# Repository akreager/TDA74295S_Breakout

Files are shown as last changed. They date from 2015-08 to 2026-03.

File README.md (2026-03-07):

# TDA7429 Breakout Board & Arduino Library

Breakout board and Arduino library for the ST TDA7429 digitally controlled audio processor with surround sound matrix.

## What is the TDA7429?

The TDA7429 is an I²C-controlled audio DSP designed for TV and Hi-Fi systems. It handles input selection, volume/tone control, surround sound processing, and speaker balance — all through a two-wire serial bus with no external microcontroller overhead beyond simple register writes.

**Key specs:**
- 3 stereo inputs with 0–31.5 dB attenuation (0.5 dB steps)
- Bass, middle, and treble control (±14 dB, 2 dB steps)
- 4 independent speaker attenuators (0–79 dB, 1 dB steps + mute)
- 3 surround modes: music, movie, simulated (256 selectable responses)
- 4 programmable phase shifters
- Monitor and auxiliary outputs
- 106 dB signal-to-noise ratio
- 7–10.2 V supply

## Repository Structure

```
├── pcb/
│   ├── TDA7429_BREAKOUT.kicad_pro      # KiCad project
│   ├── TDA7429_BREAKOUT.kicad_sch      # Schematic
│   ├── TDA7429_BREAKOUT.kicad_pcb      # PCB layout
│   ├── fp-lib-table                    # Footprint library table
│   ├── sym-lib-table                   # Symbol library table
│   ├── eagle2kicad_pcb.py              # Board conversion script
│   ├── eagle2kicad_sch.py              # Schematic conversion script
│   ├── TDA7429_KiCad_Lib/             # Custom KiCad library
│   │   ├── TDA7429.kicad_sym
│   │   └── TDA7429.pretty/
│   │       └── SDIP-42_W15.24mm_P1.778mm.kicad_mod
│   └── Archive Eagle Design/           # Original Eagle 6.5 files
│       ├── TDA7429_BREAKOUT.sch
│       ├── TDA7429_BREAKOUT.brd
│       └── TDA7429_BREAKOUT.pdf
├── TDA7429S TDA7429T.pdf               # Datasheet
├── .gitattributes
├── .gitignore
└── README.md
```

## Hardware

### Breakout Board

~50 × 50 mm board carrying the TDA7429S (SDIP-42) with all external filter components from the datasheet reference circuit. Pin headers break out:

| Header | Pins |
|---|---|
| AUDIO_IN | 3 stereo input pairs (L/R × IN1–IN3) |
| AUDIO_OUT  | L_OUT, R_OUT, AUXOUT_L, AUXOUT_R |
| MONITOR | MONITOR_L, MONITOR_R |
| DATA | SDA, SCL |
| POWER | +9V, GND |

### Connecting to Arduino

| Breakout | Arduino Uno/Nano | Arduino Mega |
|---|---|---|
| SDA | A4 | 20 |
| SCL | A5 | 21 |
| GND | GND | GND |

The TDA7429 runs at 7–10.2 V — do **not** power it from the Arduino 5V pin. Use a separate 9V supply for the breakout board. The I²C bus needs pull-up resistors to the Arduino's 3.3V or 5V (4.7kΩ typical). The chip's I²C thresholds (V_IL max 1V, V_IH min 3V) are compatible with both 3.3V and 5V logic.

## Arduino Library

### Installation

Copy the `firmware/TDA7429/` folder into your Arduino libraries directory, or use the Arduino IDE Library Manager if published.

### Quick Start

```cpp
#include <Wire.h>
#include <TDA7429.h>

TDA7429 audio;

void setup() {
  Wire.begin();
  audio.begin();

  audio.selectInput(1);          // Input 1
  audio.setInputAttenuation(0);  // 0 dB (no attenuation)
  audio.setBass(0);              // Flat
  audio.setMiddle(0);            // Flat
  audio.setTreble(0);            // Flat
  audio.setSpeakerAttenuation(TDA7429_LEFT, -20);   // -20 dB
  audio.setSpeakerAttenuation(TDA7429_RIGHT, -20);  // -20 dB
  audio.setSurroundMode(TDA7429_SURROUND_OFF);
}

void loop() {
  // Adjust volume, tone, etc. from serial commands, buttons, encoder...
}
```

### API Reference

| Method | Description |
|---|---|
| `begin()` | Initialize with default (muted) state |
| `selectInput(1–4)` | Choose stereo input pair |
| `setInputAttenuation(dB)` | 0 to -31.5 dB in 0.5 dB steps |
| `setBass(dB)` | -14 to +14 dB in 2 dB steps |
| `setMiddle(dB)` | -14 to +14 dB in 2 dB steps |
| `setTreble(dB)` | -14 to +14 dB in 2 dB steps |
| `setSpeakerAttenuation(ch, dB)` | 0 to -79 dB per channel, 1 dB steps |
| `setAuxAttenuation(ch, dB)` | 0 to -79 dB per channel, 1 dB steps |
| `setSurroundMode(mode)` | OFF, MUSIC, MOVIE, SIMULATED |
| `setEffectControl(dB)` | -6 to -21 dB surround effect level |
| `setPhaseShifters(...)` | Configure 4 phase shift resistors |
| `mute()` / `unmute()` | Mute/unmute all speaker outputs |

## Known Issues / TODO

- [ ] DIG_GND (pin 28) needs to be connected to ground in the schematic
- [ ] Audio connector ground pins (L-, R-) need explicit connection to AGND
- [ ] Consider adding bottom ground pour for improved noise performance
- [ ] Add ferrite bead between DIG_GND and AGND for digital/analog isolation

## License

Hardware design files are released under [CERN-OHL-P v2](https://ohwr.org/cern_ohl_p_v2.txt). Arduino library is released under the MIT License. See individual directories for details.

## Credits

Board design by Allen Kreager. Originally designed in Eagle 6.5, converted to KiCad 7.

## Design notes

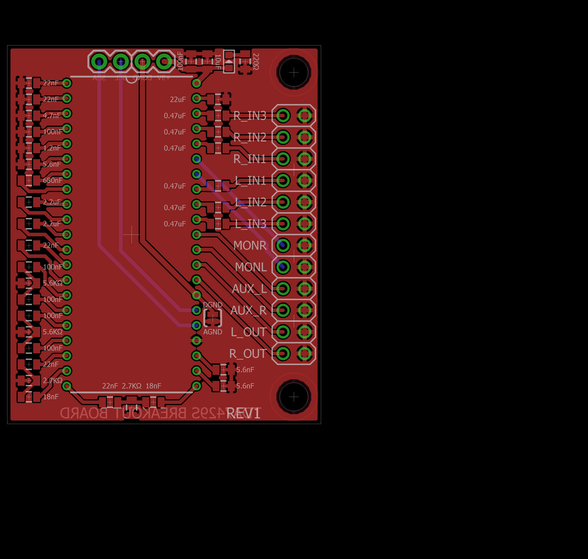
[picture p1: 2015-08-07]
Hardware/TDA7429_BREAKOUT.png

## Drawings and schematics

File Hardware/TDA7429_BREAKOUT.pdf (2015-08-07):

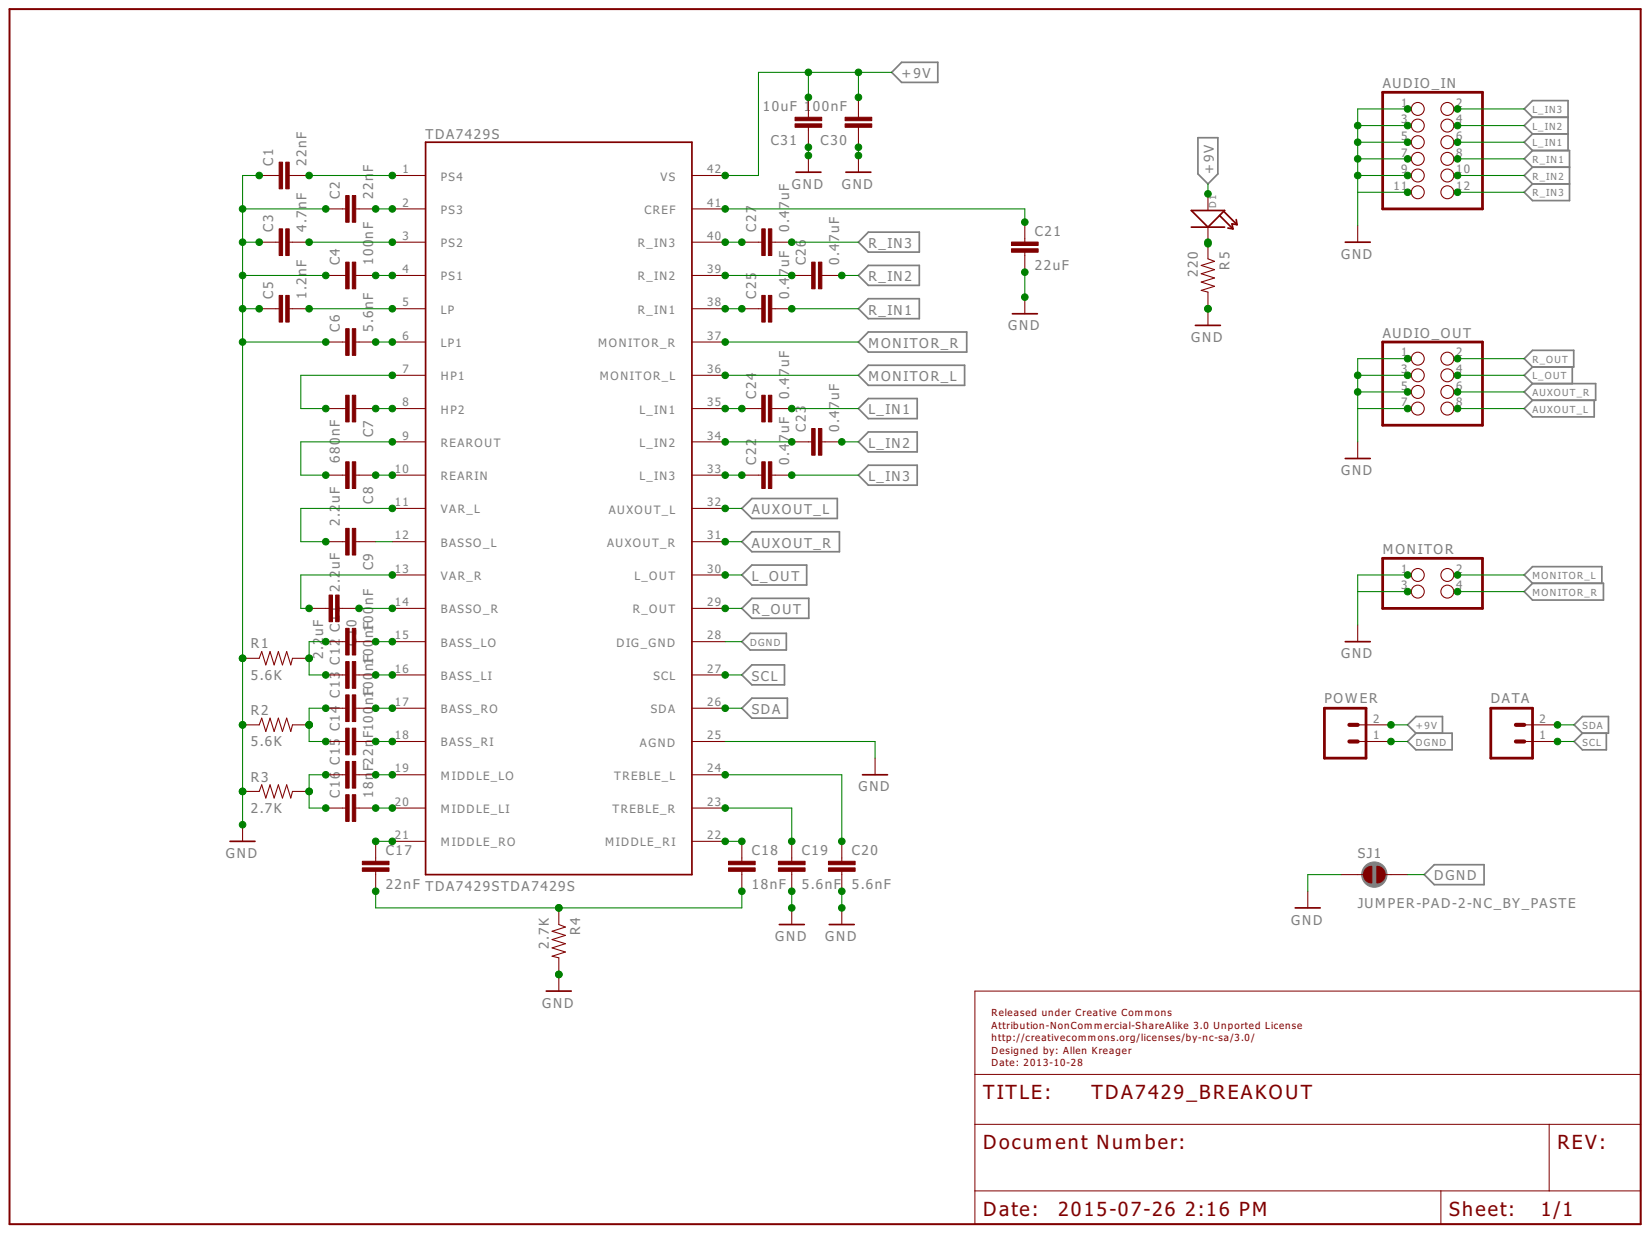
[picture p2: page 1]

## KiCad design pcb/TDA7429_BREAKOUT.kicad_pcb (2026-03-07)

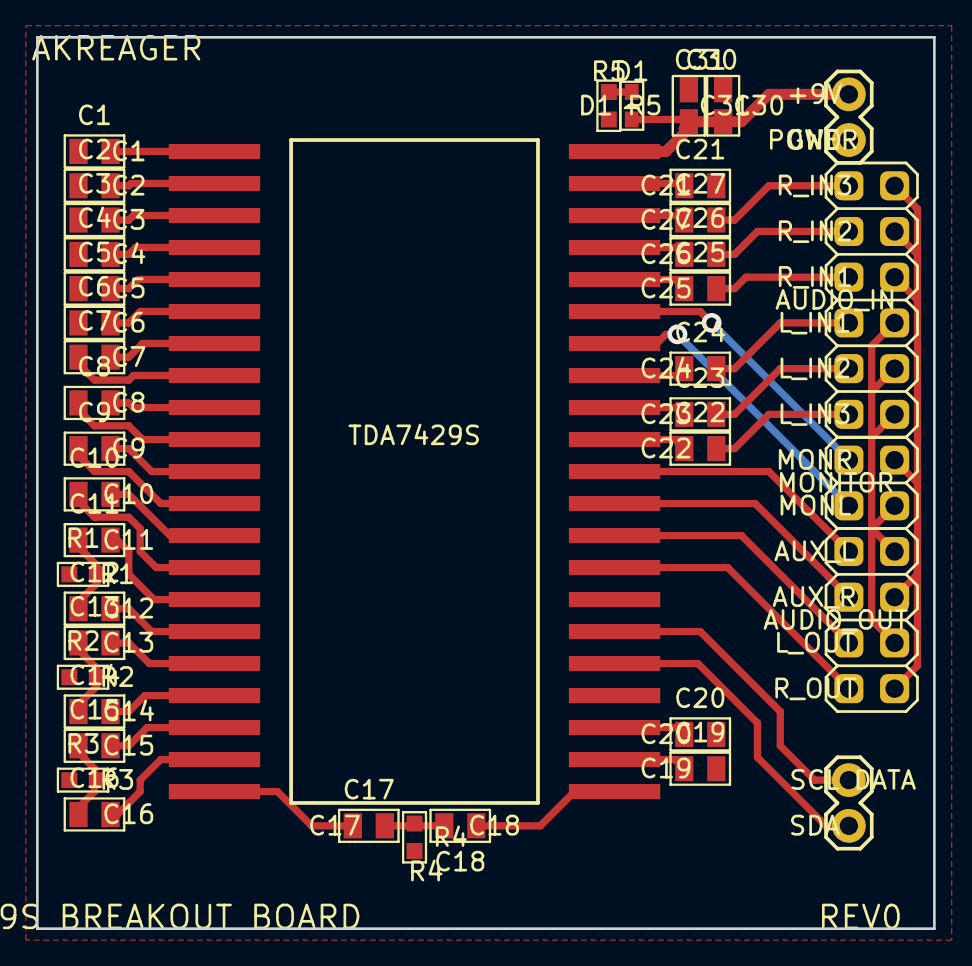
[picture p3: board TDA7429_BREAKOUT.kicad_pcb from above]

Board: 2 copper layers, 49.8 x 49.5 mm, 42 parts (0 on the bottom side), 54 nets.

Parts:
AUDIO_IN: 2X06
AUDIO_OUT: 2X04
C1, C2, C15, C17: 22nF; C0805
C3: 4.7nF; C0805
C4, C11, C12, C13, C14, C30: 100nF; C0805
C5: 1.2nF; C0805
C6, C19, C20: 5.6nF; C0805
C7: 680nF; C0805
C8, C9, C10: 2.2uF; C0805
C16, C18: 18nF; C0805
C21: 22uF; C0805
C22, C23, C24, C25, C26, C27: 0.47uF; C0805
C31: 10uF; C0805
D1: LED0603
DATA: 1X02
FRAME1: FRAME-LETTER; CREATIVE_COMMONS
MONITOR: 2X02
POWER: 1X02
R1, R2: 5.6K; R0603
R3, R4: 2.7K; R0603
R5: 220; R0603
TDA7429S: TDA7429S_SURFACE; SDIP42_SURFACE

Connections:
+9V: C30.2, C31.2, D1.+, POWER.2, TDA7429S.42
AUXOUT_L: AUDIO_OUT.8, TDA7429S.32
AUXOUT_R: AUDIO_OUT.6, TDA7429S.31
GND: C1.1, C2.1, C3.1, C4.1, C5.1, C6.1, C19.2, C20.2, C21.2, C30.1, C31.1, POWER.1, R1.1, R2.1, R3.1, R4.2, R5.2, TDA7429S.25
HP1: C7.2, TDA7429S.7
L-: AUDIO_IN.1, AUDIO_IN.3, AUDIO_IN.5, AUDIO_OUT.3, AUDIO_OUT.7, MONITOR.1
L_IN1: AUDIO_IN.6, C24.2
L_IN2: AUDIO_IN.4, C23.2
L_IN3: AUDIO_IN.2, C22.2
L_OUT: AUDIO_OUT.4, TDA7429S.30
MONITOR_L: MONITOR.2, TDA7429S.36
MONITOR_R: MONITOR.4, TDA7429S.37
unnamed: D1.-, R5.1
unnamed: C9.1, TDA7429S.12
unnamed: C3.2, TDA7429S.3
unnamed: C1.2, TDA7429S.1
unnamed: C2.2, TDA7429S.2
unnamed: C4.2, TDA7429S.4
unnamed: C5.2, TDA7429S.5
unnamed: C6.2, TDA7429S.6
unnamed: C7.1, TDA7429S.8
unnamed: C8.1, TDA7429S.10
unnamed: C10.1, TDA7429S.14
unnamed: C11.2, TDA7429S.15
unnamed: C11.1, C12.1, R1.2
unnamed: C12.2, TDA7429S.16
unnamed: C13.2, TDA7429S.17
unnamed: C13.1, C14.1, R2.2
unnamed: C14.2, TDA7429S.18
unnamed: C15.2, TDA7429S.19
unnamed: C16.2, TDA7429S.20
unnamed: C15.1, C16.1, R3.2
unnamed: C17.1, TDA7429S.21
unnamed: C18.1, TDA7429S.22
unnamed: C17.2, C18.2, R4.1
unnamed: C19.1, TDA7429S.23
unnamed: C20.1, TDA7429S.24
unnamed: C27.1, TDA7429S.40
unnamed: C26.1, TDA7429S.39
unnamed: C25.1, TDA7429S.38
unnamed: C24.1, TDA7429S.35
unnamed: C23.1, TDA7429S.34
unnamed: C22.1, TDA7429S.33
unnamed: C21.1, TDA7429S.41
R-: AUDIO_IN.7, AUDIO_IN.9, AUDIO_IN.11, AUDIO_OUT.1, AUDIO_OUT.5, MONITOR.3
REAROUT: C8.2, TDA7429S.9
R_IN1: AUDIO_IN.8, C25.2
R_IN2: AUDIO_IN.10, C26.2
R_IN3: AUDIO_IN.12, C27.2
R_OUT: AUDIO_OUT.2, TDA7429S.29
SCL: DATA.1, TDA7429S.27
SDA: DATA.2, TDA7429S.26
VAR_L: C9.2, TDA7429S.11
VAR_R: C10.2, TDA7429S.13

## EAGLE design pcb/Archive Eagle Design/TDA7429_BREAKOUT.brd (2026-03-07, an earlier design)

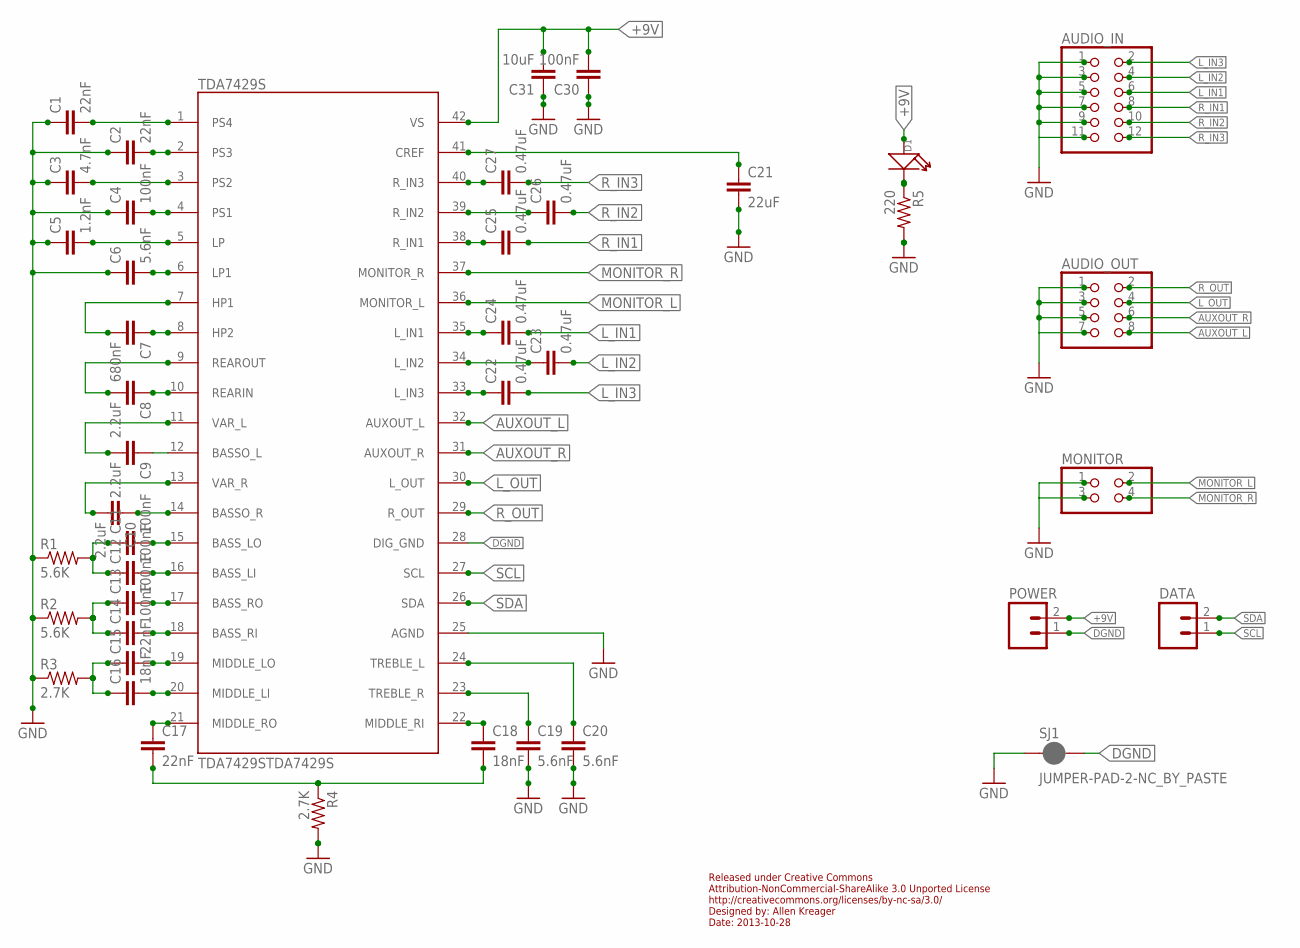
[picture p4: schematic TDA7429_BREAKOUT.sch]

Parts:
AUDIO_IN: PINHD-2X6; 2X06
AUDIO_OUT: PINHD-2X4; 2X04
C1, C2, C15, C17: 22nF; 0805
C3: 4.7nF; 0805
C4, C11, C12, C13, C14, C30: 100nF; 0805
C5: 1.2nF; 0805
C6, C19, C20: 5.6nF; 0805
C7: 680nF; 0805
C8, C9, C10: 2.2uF; 0805
C16, C18: 18nF; 0805
C21: 22uF; 0805
C22, C23, C24, C25, C26, C27: 0.47uF; 0805
C31: 10uF; 0805
D1: LED; LED0603
DATA: M02PTH; 1X02
MONITOR: PINHD-2X2; 2X02
POWER: M02PTH; 1X02
R1, R2: 5.6K; 0805
R3, R4: 2.7K; 0805
R5: 220; 0805
SJ1: JUMPER-PAD-2-NC_BY_PASTE; PAD-JUMPER-2-NC_BY_PASTE_YES_SILK
TDA7429S: TDA7429STDA7429S; SDIP42

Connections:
+9V: C30.2, C31.2, D1.+, POWER.2, TDA7429S.42 (VS)
AUXOUT_L: AUDIO_OUT.8, TDA7429S.32 (AUXOUT_L)
AUXOUT_R: AUDIO_OUT.6, TDA7429S.31 (AUXOUT_R)
DGND: POWER.1, SJ1.2, TDA7429S.28 (DIG_GND)
GND: AUDIO_IN.1, AUDIO_IN.3, AUDIO_IN.5, AUDIO_IN.7, AUDIO_IN.9, AUDIO_IN.11, AUDIO_OUT.1, AUDIO_OUT.3, AUDIO_OUT.5, AUDIO_OUT.7, C1.1, C2.1, C3.1, C4.1, C5.1, C6.1, C19.2, C20.2, C21.2, C30.1, C31.1, MONITOR.1, MONITOR.3, R1.1, R2.1, R3.1, R4.2, R5.2, SJ1.1, TDA7429S.25 (AGND)
HP1: C7.2, TDA7429S.7 (HP1)
L_IN1: AUDIO_IN.6, C24.2
L_IN2: AUDIO_IN.4, C23.2
L_IN3: AUDIO_IN.2, C22.2
L_OUT: AUDIO_OUT.4, TDA7429S.30 (L_OUT)
MONITOR_L: MONITOR.2, TDA7429S.36 (MONITOR_L)
MONITOR_R: MONITOR.4, TDA7429S.37 (MONITOR_R)
unnamed: D1.-, R5.1
unnamed: C9.1, TDA7429S.12 (BASSO_L)
unnamed: C3.2, TDA7429S.3 (PS2)
unnamed: C1.2, TDA7429S.1 (PS4)
unnamed: C2.2, TDA7429S.2 (PS3)
unnamed: C4.2, TDA7429S.4 (PS1)
unnamed: C5.2, TDA7429S.5 (LP)
unnamed: C6.2, TDA7429S.6 (LP1)
unnamed: C7.1, TDA7429S.8 (HP2)
unnamed: C8.1, TDA7429S.10 (REARIN)
unnamed: C10.1, TDA7429S.14 (BASSO_R)
unnamed: C11.2, TDA7429S.15 (BASS_LO)
unnamed: C11.1, C12.1, R1.2
unnamed: C12.2, TDA7429S.16 (BASS_LI)
unnamed: C13.2, TDA7429S.17 (BASS_RO)
unnamed: C13.1, C14.1, R2.2
unnamed: C14.2, TDA7429S.18 (BASS_RI)
unnamed: C15.2, TDA7429S.19 (MIDDLE_LO)
unnamed: C16.2, TDA7429S.20 (MIDDLE_LI)
unnamed: C15.1, C16.1, R3.2
unnamed: C17.1, TDA7429S.21 (MIDDLE_RO)
unnamed: C18.1, TDA7429S.22 (MIDDLE_RI)
unnamed: C17.2, C18.2, R4.1
unnamed: C19.1, TDA7429S.23 (TREBLE_R)
unnamed: C20.1, TDA7429S.24 (TREBLE_L)
unnamed: C27.1, TDA7429S.40 (R_IN3)
unnamed: C26.1, TDA7429S.39 (R_IN2)
unnamed: C25.1, TDA7429S.38 (R_IN1)
unnamed: C24.1, TDA7429S.35 (L_IN1)
unnamed: C23.1, TDA7429S.34 (L_IN2)
unnamed: C22.1, TDA7429S.33 (L_IN3)
unnamed: C21.1, TDA7429S.41 (CREF)
REAROUT: C8.2, TDA7429S.9 (REAROUT)
R_IN1: AUDIO_IN.8, C25.2
R_IN2: AUDIO_IN.10, C26.2
R_IN3: AUDIO_IN.12, C27.2
R_OUT: AUDIO_OUT.2, TDA7429S.29 (R_OUT)
SCL: DATA.1, TDA7429S.27 (SCL)
SDA: DATA.2, TDA7429S.26 (SDA)
VAR_L: C9.2, TDA7429S.11 (VAR_L)
VAR_R: C10.2, TDA7429S.13 (VAR_R)

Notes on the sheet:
Released under Creative Commons Attribution-NonCommercial-ShareAlike 3.0 Unported License http://creativecommons.org/licenses/by-nc-sa/3.0/ Designed by: Allen Kreager Date: 2013-10-28

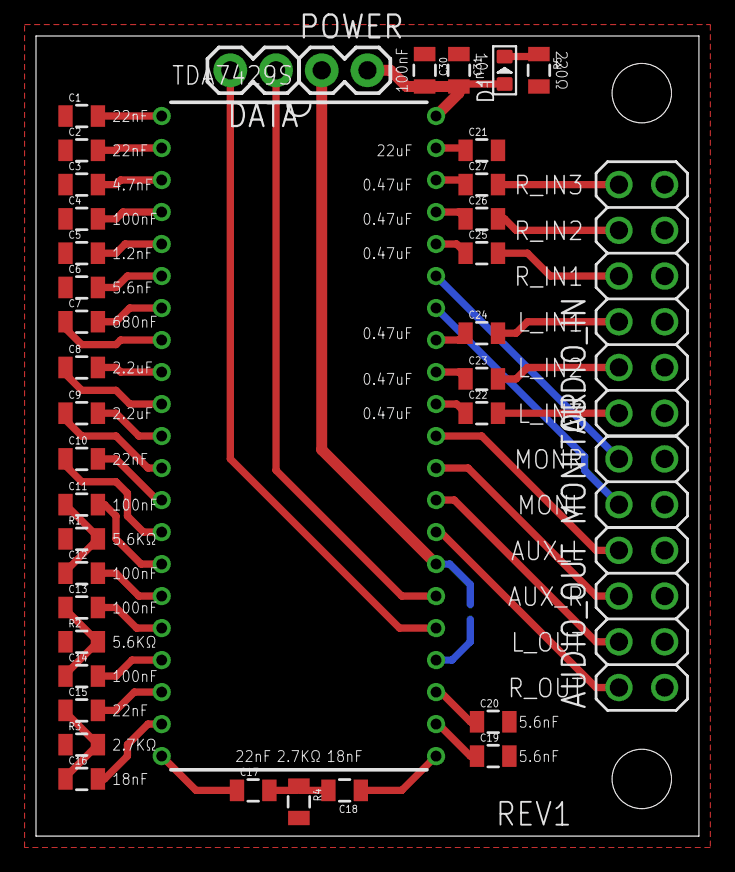
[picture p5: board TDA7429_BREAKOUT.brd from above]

Board: 2 copper layers, 36.8 x 44.5 mm, 44 parts (1 on the bottom side), 53 nets.

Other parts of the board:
U$1, U$2: STAND-OFF

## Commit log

2015-08-07 TDA7429 audio DSP IC breakout board
    [TDA7429_BREAKOUT.brd, TDA7429_BREAKOUT.sch]
2026-03-07 revive project and prepare for migration to kicad design and arduino library
    [TDA7429_BREAKOUT.brd, TDA7429_BREAKOUT.sch]
2026-03-07 inital kicad conversion
    [TDA7429_BREAKOUT.kicad_pcb, TDA7429_BREAKOUT.kicad_sch]
2026-03-07 Add symbol that matches datasheet test circuit.
2026-03-07 start redesigning schematic
    [TDA7429_BREAKOUT.kicad_sch]
2026-03-08 update schematic
    [TDA7429_BREAKOUT.kicad_sch, power_supply.kicad_sch]
2026-03-08 tweak schematic, add i2c pullup resistors.
    [TDA7429_BREAKOUT.kicad_sch, power_supply.kicad_sch]

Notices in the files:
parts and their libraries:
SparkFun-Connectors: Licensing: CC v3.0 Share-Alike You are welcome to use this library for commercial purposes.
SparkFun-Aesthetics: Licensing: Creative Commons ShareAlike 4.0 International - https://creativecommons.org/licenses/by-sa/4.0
